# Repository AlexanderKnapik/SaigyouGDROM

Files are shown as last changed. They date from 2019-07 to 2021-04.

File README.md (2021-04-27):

SaigyouGDROM
========

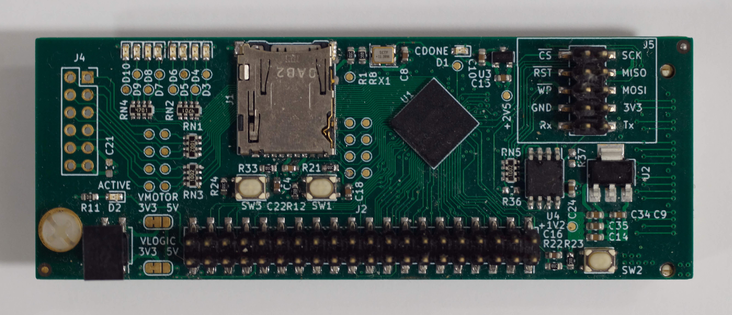
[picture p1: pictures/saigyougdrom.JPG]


SaigyouGDROM is a redesigned hardware implementation for Marcus Comstedt's
"iceGDROM". The aim of the project is to use the original software and gateware,
but with the hardware redesigned for a complete package.

This is currently a work in progress. Although the first revision prototypes have
been manufactured, there is still a lot to do in regards for testing and
recompiling the firmware and gateware for the new hardware.

For more information, please do visit the [original project](https://github.com/zeldin/iceGDROM).

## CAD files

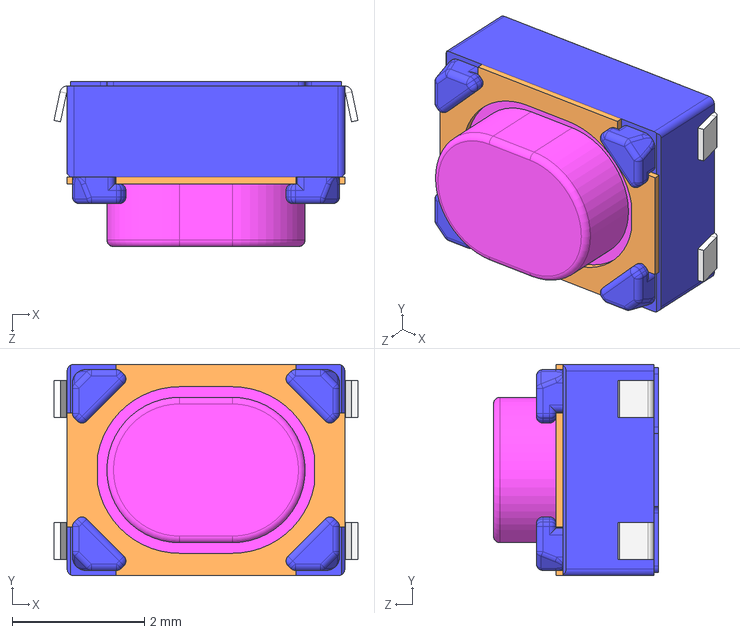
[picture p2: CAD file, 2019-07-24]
pcb/iceGDROM/3D/SKRPAB.STEP
4.60 x 3.20 x 2.50 mm

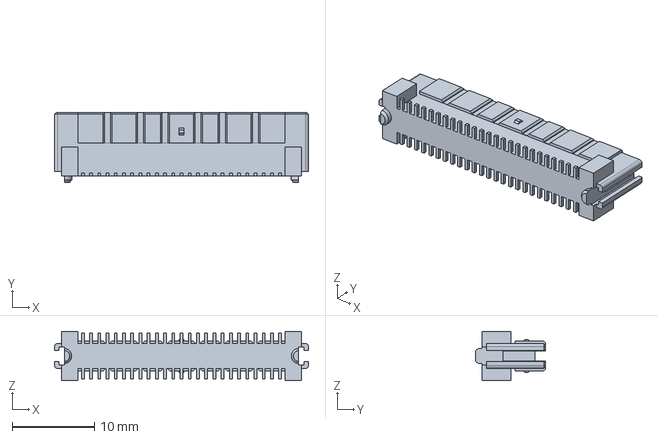
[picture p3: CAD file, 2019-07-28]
pcb/iceGDROM/3D/526020579.stp
30.9 x 8.50 x 6.00 mm

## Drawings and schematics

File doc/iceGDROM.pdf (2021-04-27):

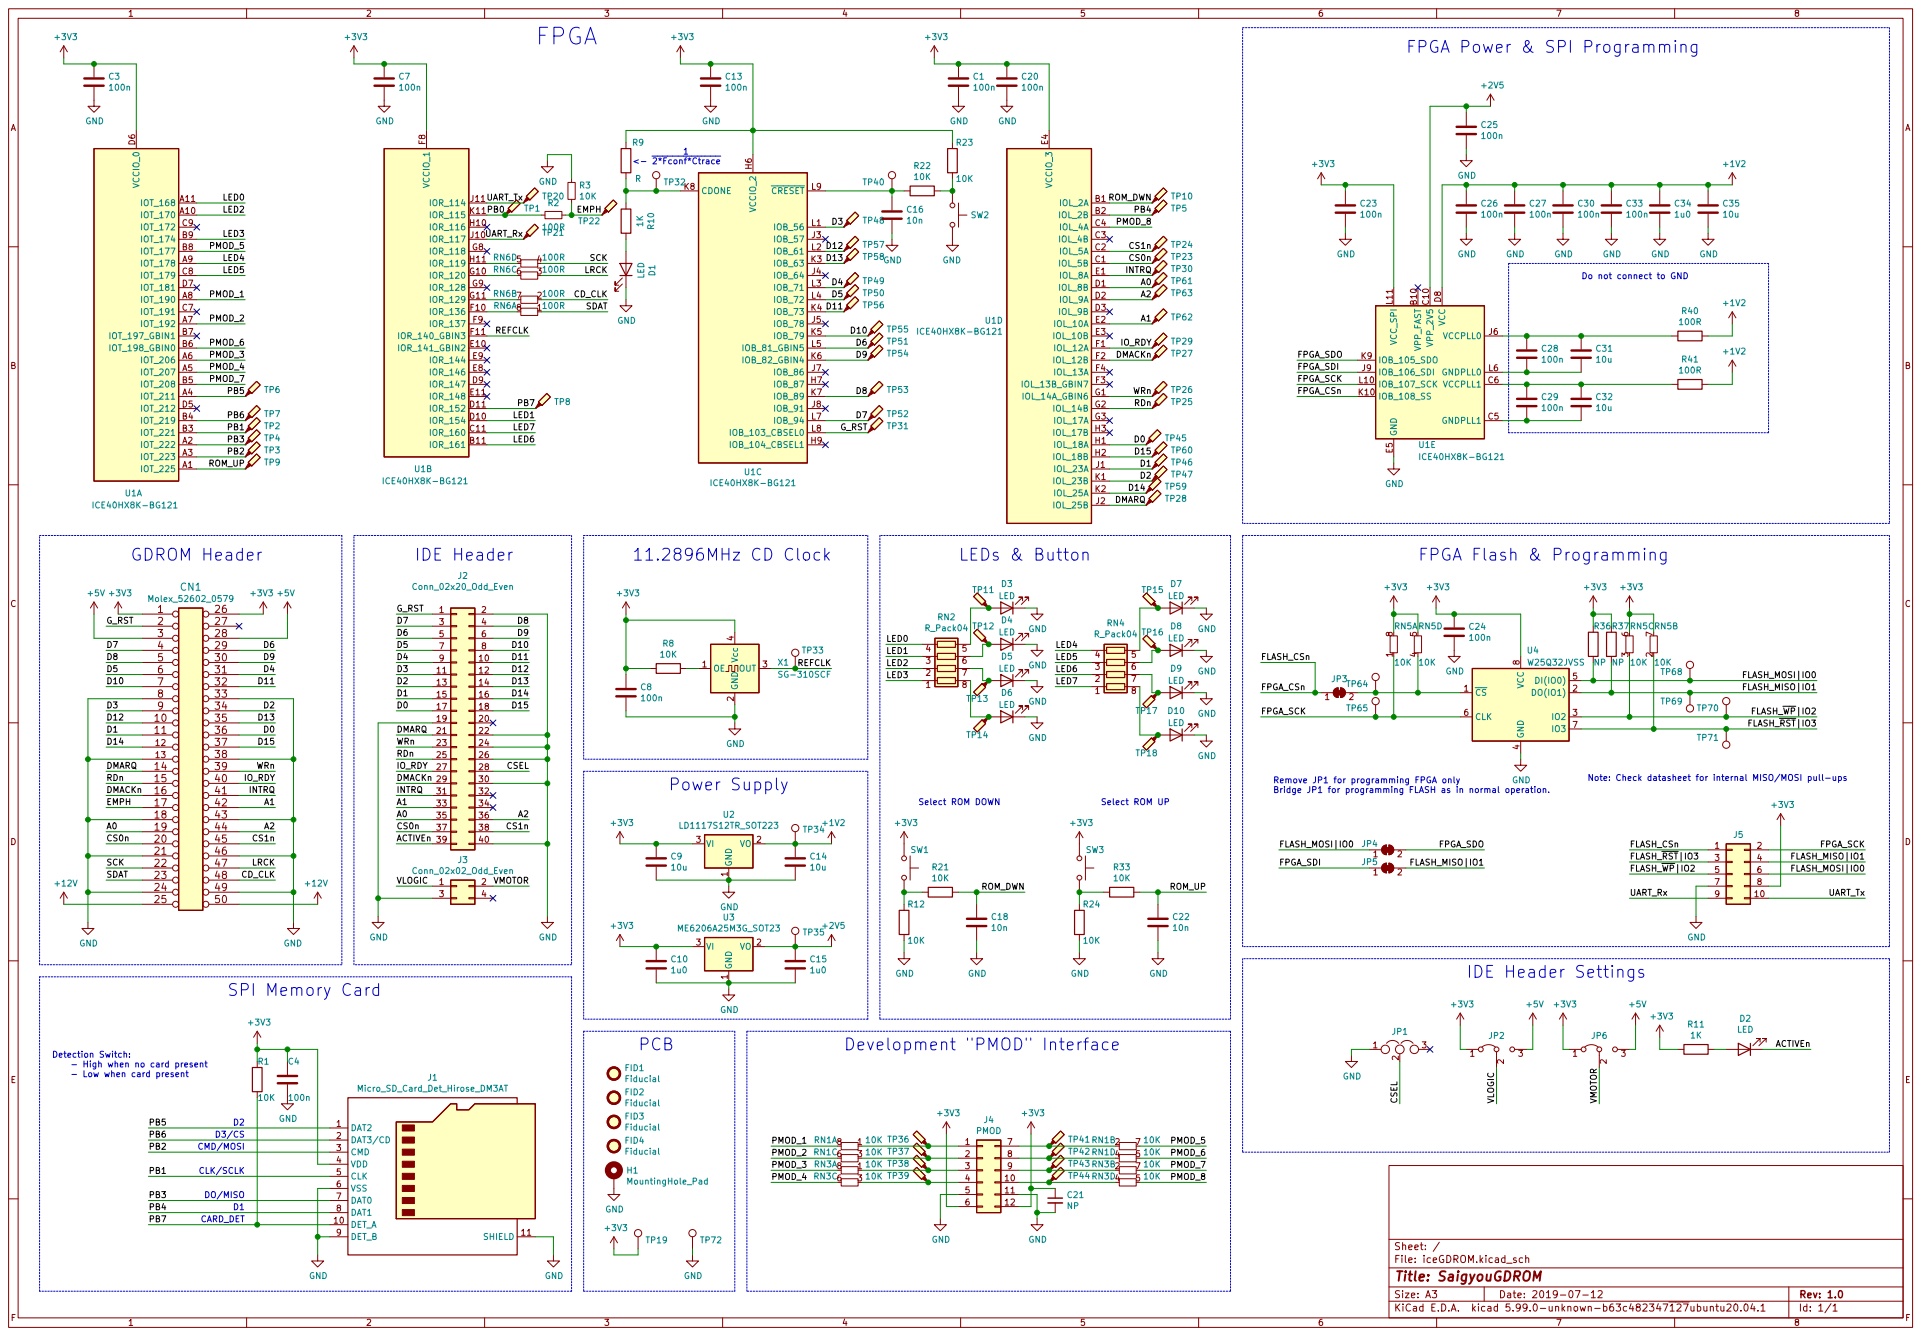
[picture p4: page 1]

FPGA Power & SPI Programming

Do not connect to GND

Note: Check datasheet for internal MISO/MOSI pull-ups

Remove JP1 for programming FPGA only
Bridge JP1 for programming FLASH as in normal operation.

D2 CARD_DET Detection Switch:
- High when no card present

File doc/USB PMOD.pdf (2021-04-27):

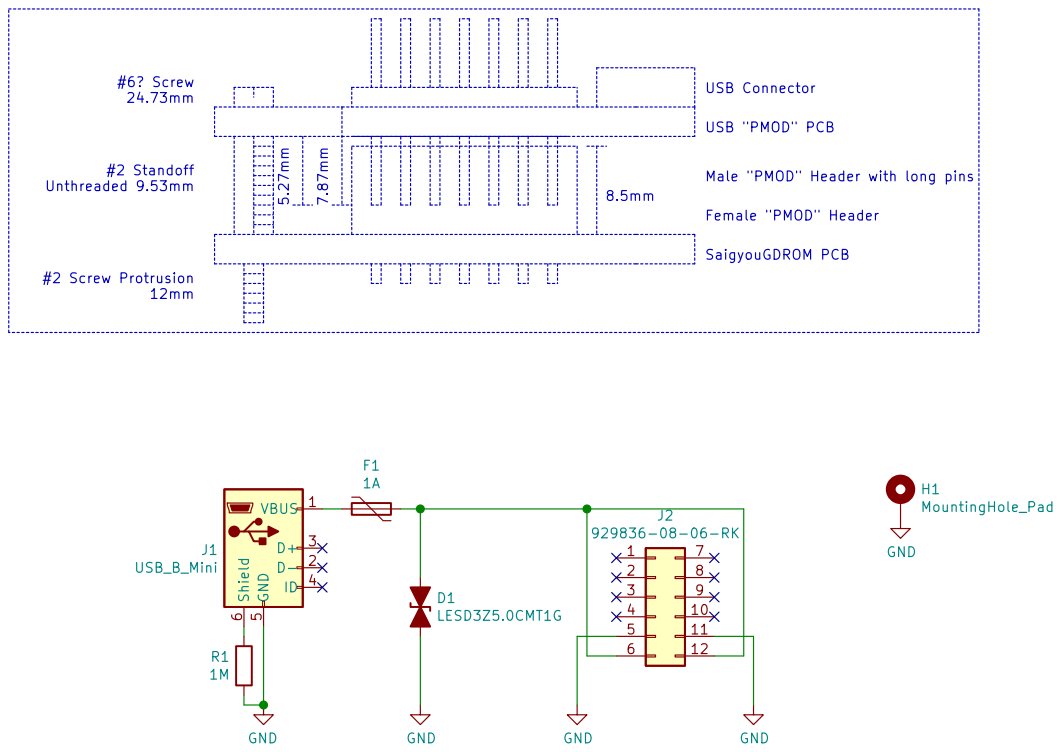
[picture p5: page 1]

File: USB PMOD.kicad_sch Sheet: /
Id: 1/1 Title:

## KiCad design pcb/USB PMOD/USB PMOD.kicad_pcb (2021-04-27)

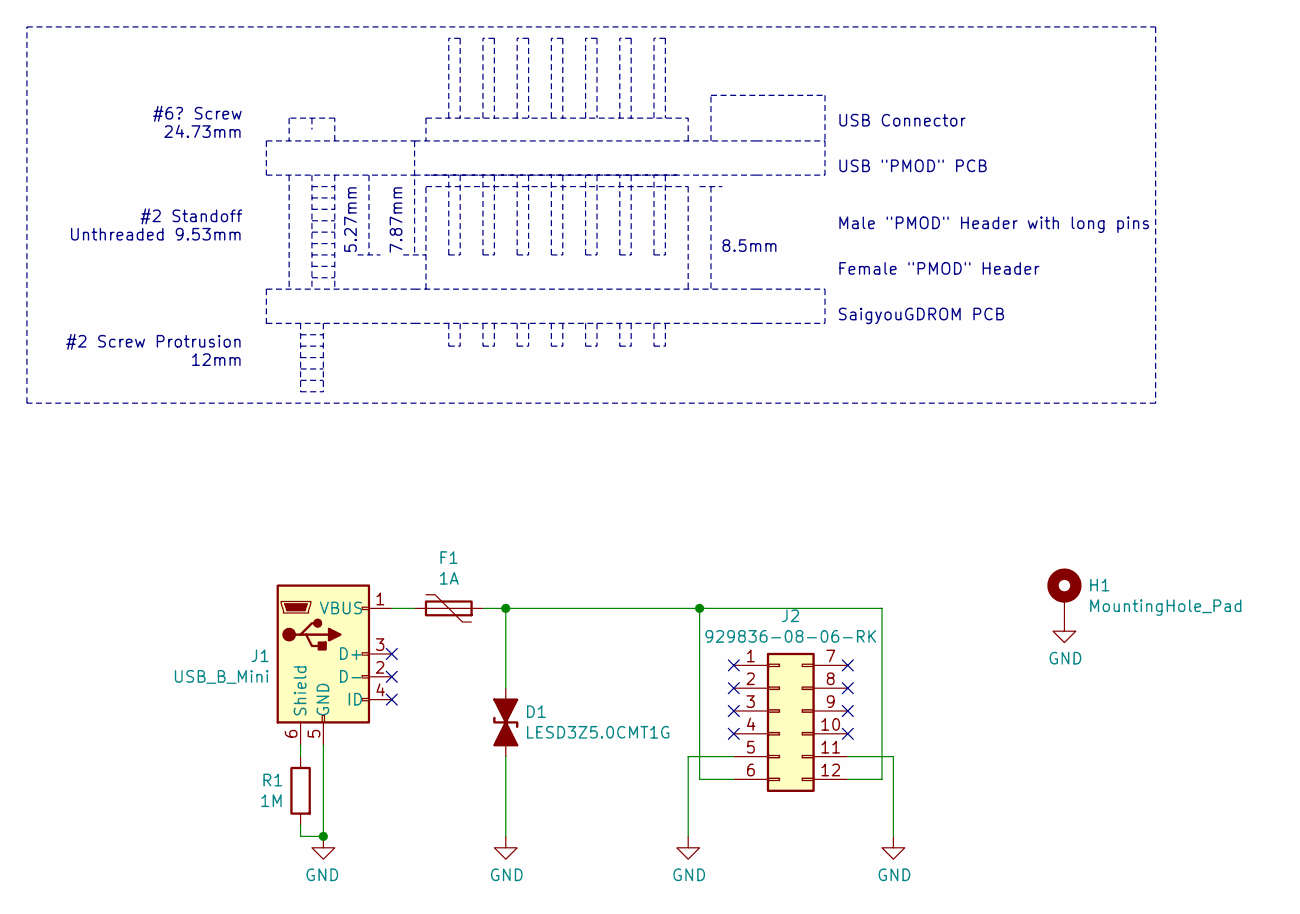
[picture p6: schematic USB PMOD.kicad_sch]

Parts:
D1: LESD3Z5.0CMT1G; D_SOD-323
F1: 1A; Fuse_1210_3225Metric_Castellated
H1: MountingHole_Pad; MountingHole_3.2mm_M3_Pad_Via
J1: USB_B_Mini; USB_Mini-B_Molex_657031020_Horizontal
J2: 929836-08-06-RK; PMOD_Host_2x06_P2.54mm_Vertical
R1: 1M; R_0603_1608Metric

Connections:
GND: D1.1 (A1), H1.1, J1.5 (GND), J2.5, J2.11, R1.2
unnamed: D1.2 (A2), F1.1, J2.6, J2.12
unnamed: F1.2, J1.1 (VBUS)
unnamed: J1.6 (Shield), R1.1

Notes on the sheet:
#6? Screw 24.73mm
#2 Standoff Unthreaded 9.53mm
#2 Screw Protrusion 12mm
5.27mm
7.87mm
8.5mm
USB Connector
USB "PMOD" PCB
Male "PMOD" Header with long pins
Female "PMOD" Header
SaigyouGDROM PCB

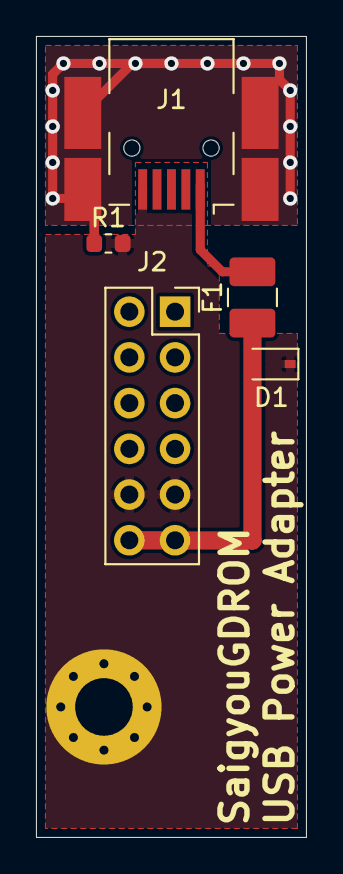
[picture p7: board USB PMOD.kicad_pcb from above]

Board: 2 copper layers, 15.0 x 44.5 mm, 6 parts (0 on the bottom side), 4 nets.

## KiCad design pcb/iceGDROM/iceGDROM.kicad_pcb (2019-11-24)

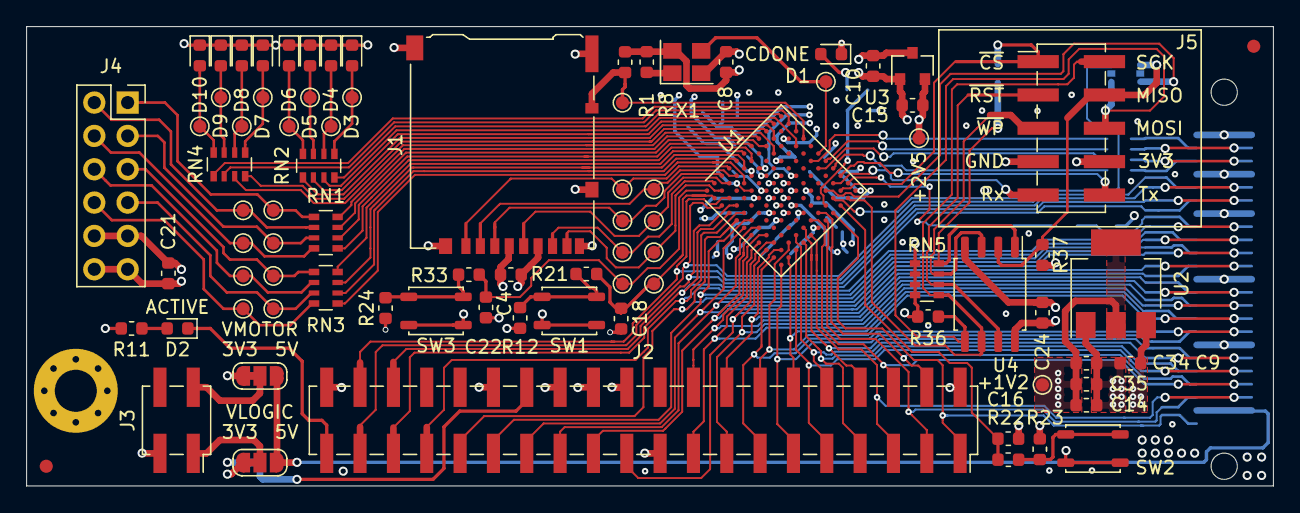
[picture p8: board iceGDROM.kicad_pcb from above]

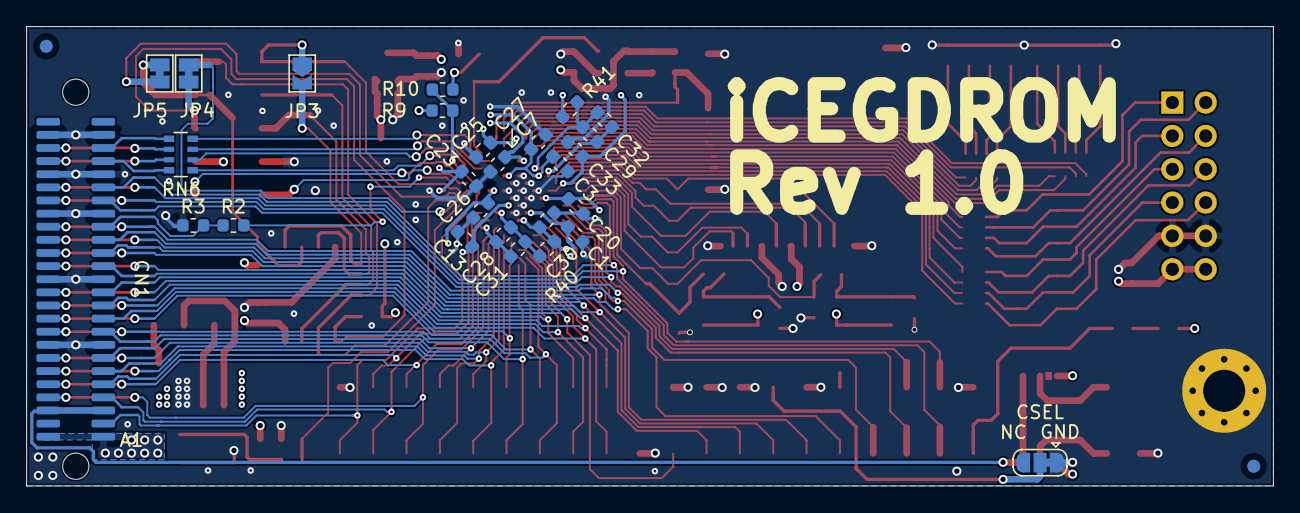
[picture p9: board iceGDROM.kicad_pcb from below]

Board: 4 copper layers, 95.0 x 35.0 mm, 114 parts (29 on the bottom side), 113 nets.

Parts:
+1V2, +2V5: TestPoint; TestPoint_Pad_D1.0mm
C1, C3, C4, C7, C8, C13, C20, C23, C24, C25, C26, C27, C28, C29, C30, C33: 100n; C_0603_1608Metric
C9, C14, C31, C32, C35: 10u; C_0603_1608Metric
C10, C15, C34: 1u0; C_0603_1608Metric
C16, C18, C22: 10n; C_0603_1608Metric
C21: NP; C_0603_1608Metric
CN1: Molex_52602_0579; Molex_052602_0579
D1, D2, D3, D4, D5, D6, D7, D8, D9, D10: LED; LED_0603_1608Metric
FID1, FID2, FID3, FID4: Fiducial; Fiducial_1mm_Mask2mm
H1: MountingHole_Pad; MountingHole_3.2mm_M3_Pad_Via
J1: Micro_SD_Card_Det_Hirose_DM3AT; microSD_HC_Hirose_DM3AT-SF-PEJM5
J2: Conn_02x20_Odd_Even; PinSocket_2x20_P2.54mm_Vertical_SMD
J3: Conn_02x02_Odd_Even; PinSocket_2x02_P2.54mm_Vertical_SMD
J4: PMOD; PMOD_Host_2x06_P2.54mm_Vertical
J5: Conn_02x05_Odd_Even; PinHeader_2x05_P2.54mm_Vertical_SMD
JP1: Jumper_NC_Dual; SolderJumper-3_P1.3mm_Bridged12_RoundedPad1.0x1.5mm
JP2, JP6: Jumper_3_Bridged12; SolderJumper-3_P1.3mm_Bridged12_RoundedPad1.0x1.5mm_NumberL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
JP3: SolderJumper_2_Bridged; SolderJumper-2_P1.3mm_Open_TrianglePad1.0x1.5mm
JP4, JP5: Jumper_NC_Small; SolderJumper-2_P1.3mm_Bridged_Pad1.0x1.5mm
R1, R3, R8, R12, R21, R22, R23, R24, R33: 10K; R_0603_1608Metric
R2, R40, R41: 100R; R_0603_1608Metric
R9: R; R_0603_1608Metric
R10, R11: 1K; R_0603_1608Metric
R36, R37: NP; R_0603_1608Metric
RN1, RN3, RN5: 10K; R_Array_Convex_4x0603
RN2, RN4: R_Pack04; R_Array_Convex_4x0603
RN6: 100R; R_Array_Convex_4x0603
SW1, SW2, SW3: SW_Push; SW_Push_SPST_NO_Alps_SKRP
TP2, TP3, TP4, TP5, TP6, TP7, TP8, TP9, TP10, TP11, TP12, TP13, TP14, TP15, TP16, TP17, TP18, TP36, TP37, TP38, TP39, TP41, TP42, TP43, TP44: TestPoint_Probe; TestPoint_Pad_D1.0mm
TP33: TestPoint; TestPoint_Pad_D1.0mm
U1: ICE40HX8K-BG121; BGA-121_9.0x9.0mm_Layout11x11_P0.8mm_Ball0.4mm_Pad0.35mm_NS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
U2: LD1117S12TR_SOT223; SOT-223-3_TabPin2
U3: ME6206A25M3G_SOT23; SOT-23
U4: W25Q32JVSS; SOIC-8_5.23x5.23mm_P1.27mm
X1: SG-310SCF; Crystal_SMD_3225-4Pin_3.2x2.5mm

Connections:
+1V2: +1V2.1, C14.1, C26.1, C27.1, C30.1, C33.1, C34.1, C35.1, R40.1, R41.1, U1.D4, U1.D8, U1.H4, U1.H8, U2.2
+2V5: +2V5.1, C15.1, C25.1, U1.C10, U3.2
+3V3: C1.2, C3.2, C4.1, C7.2, C8.1, C9.1, C10.1, C13.2, C20.2, C21.1, C23.1, C24.1, CN1.1, CN1.26, J1.4, J4.6, J4.12, J5.8, JP2.1, JP6.1, R1.1, R8.2, R9.2, R11.2, R23.2, R36.1, R37.1, RN5.5, RN5.6, RN5.7, RN5.8, SW1.1, SW3.1, U1.D6, U1.E4, U1.F8, U1.G4, U1.H6, U1.L11, U2.3, U3.3, U4.8, X1.4
+5V: CN1.3, CN1.28, JP2.3, JP6.3
+12V: CN1.25, CN1.50
/A0: CN1.19, J2.35, U1.D1
/A1: CN1.42, J2.33, U1.E2
/A2: CN1.44, J2.36, U1.D2
/ACTIVEn: D2.1, J2.39
/CD_CLK: CN1.48, RN6.2
/CS0n: CN1.20, J2.37, U1.C1
/CS1n: CN1.45, J2.38, U1.C2
/CSEL: J2.28, JP1.2
/D0: CN1.36, J2.17, U1.H1
/D1: CN1.11, J2.15, U1.J1
/D2: CN1.34, J2.13, U1.K1
/D3: CN1.9, J2.11, U1.L1
/D4: CN1.31, J2.9, U1.L3
/D5: CN1.6, J2.7, U1.L4
/D6: CN1.29, J2.5, U1.L5
/D7: CN1.4, J2.3, U1.L7
/D8: CN1.5, J2.4, U1.K7
/D9: CN1.30, J2.6, U1.K6
/D10: CN1.7, J2.8, U1.K5
/D11: CN1.32, J2.10, U1.K4
/D12: CN1.10, J2.12, U1.L2
/D13: CN1.35, J2.14, U1.K3
/D14: CN1.12, J2.16, U1.K2
/D15: CN1.37, J2.18, U1.H2
/DMACKn: CN1.16, J2.29, U1.F2
/DMARQ: CN1.14, J2.21, U1.J2
/EMPH: CN1.17, R2.1, R3.2
/FLASH_CSn: J5.1, JP3.1, U1.K10
/FLASH_MISO|IO1: J5.4, JP5.2, R37.2, U4.2
/FLASH_MOSI|IO0: J5.6, JP4.1, R36.2, U4.5
/FLASH_~RST~|IO3: J5.3, RN5.2, U4.7
/FLASH_~WP~|IO2: J5.5, RN5.3, U4.3
/FPGA_SCK: J5.2, RN5.1, U1.L10, U4.6
/FPGA_SDI: JP5.1, U1.J9
/FPGA_SDO: JP4.2, U1.K9
/G_RST: CN1.2, J2.1, U1.L8
/INTRQ: CN1.41, J2.31, U1.E1
/IO_RDY: CN1.40, J2.27, U1.F1
/LED0: RN2.4, U1.A11
/LED1: RN2.3, U1.D10
/LED2: RN2.2, U1.A10
/LED3: RN2.1, U1.B9
/LED4: RN4.4, U1.A9
/LED5: RN4.3, U1.C8
/LED6: RN4.2, U1.B11
/LED7: RN4.1, U1.C11
/LRCK: CN1.47, RN6.3
/PB0: R2.2, U1.K11
/PB1: J1.5, TP2.1, U1.B3
/PB2: J1.3, TP3.1, U1.A3
/PB3: J1.7, TP4.1, U1.A2
/PB4: J1.8, TP5.1, U1.B2
/PB5: J1.1, TP6.1, U1.A4
/PB6: J1.2, TP7.1, U1.B4
/PB7: J1.10, R1.2, TP8.1, U1.D11
/PMOD_1: RN1.8, U1.A8
/PMOD_2: RN1.6, U1.A7
/PMOD_3: RN3.8, U1.A6
/PMOD_4: RN3.6, U1.A5
/PMOD_5: RN1.7, U1.B8
/PMOD_6: RN1.5, U1.B6
/PMOD_7: RN3.7, U1.B5
/PMOD_8: RN3.5, U1.C4
/RDn: CN1.15, J2.25, U1.G2
/REFCLK: TP33.1, U1.F11, X1.3
/ROM_DWN: C18.1, R21.1, TP10.1, U1.B1
/ROM_UP: C22.1, R33.1, TP9.1, U1.A1
/SCK: CN1.22, RN6.4
/SDAT: CN1.23, RN6.1
/UART_Rx: J5.9, U1.J10
/UART_Tx: J5.10, U1.J11
/VLOGIC: J3.1, JP2.2
/VMOTOR: J3.2, JP6.2
/WRn: CN1.39, J2.23, U1.G1
GND: C1.1, C3.1, C4.2, C7.1, C8.2, C9.2, C10.2, C13.1, C14.2, C15.2, C16.1, C18.2, C20.1, C21.2, C22.2, C23.2, C24.2, C25.2, C26.2, C27.2, C30.2, C33.2, C34.2, C35.2, CN1.8, CN1.13, CN1.18, CN1.21, CN1.24, CN1.33, CN1.38, CN1.43, CN1.46, CN1.49, D1.1, D3.1, D4.1, D5.1, D6.1, D7.1, D8.1, D9.1, D10.1, H1.1, J1.6, J1.9, J1.11, J2.2, J2.19, J2.22, J2.24, J2.26, J2.30, J2.40, J3.3, J4.5, J4.11, J5.7, JP1.1, R3.1, R12.1, R24.1, SW2.2, U1.E5, U1.E6, U1.E7, U1.F5, U1.F6, U1.F7, U1.G5, U1.G6, U1.G7, U1.H5, U2.1, U3.1, U4.4, X1.2
unnamed: C16.2, R22.1, U1.L9
unnamed: C28.1, C31.1, R40.2, U1.J6
unnamed: C28.2, C31.2, U1.L6
unnamed: C29.1, C32.1, R41.2, U1.C6
unnamed: C29.2, C32.2, U1.C5
unnamed: D1.2, R10.2
unnamed: D2.2, R11.1
unnamed: D3.2, RN2.5, TP11.1
unnamed: D4.2, RN2.6, TP12.1
unnamed: D5.2, RN2.7, TP13.1
unnamed: D6.2, RN2.8, TP14.1
unnamed: D7.2, RN4.5, TP15.1
unnamed: D8.2, RN4.6, TP16.1
unnamed: D9.2, RN4.7, TP17.1
unnamed: D10.2, RN4.8, TP18.1
unnamed: J4.1, RN1.1, TP36.1
unnamed: J4.2, RN1.3, TP37.1
unnamed: J4.3, RN3.1, TP38.1
unnamed: J4.4, RN3.3, TP39.1
unnamed: J4.7, RN1.2, TP41.1
unnamed: J4.8, RN1.4, TP42.1
unnamed: J4.9, RN3.2, TP43.1
unnamed: J4.10, RN3.4, TP44.1
unnamed: JP3.2, RN5.4, U4.1
unnamed: R8.1, X1.1
unnamed: R9.1, R10.1, U1.K8
unnamed: R12.2, R21.2, SW1.2
unnamed: R22.2, R23.1, SW2.1
unnamed: R24.2, R33.2, SW3.2
unnamed: RN6.5, U1.H11
unnamed: RN6.6, U1.G10
unnamed: RN6.7, U1.G11
unnamed: RN6.8, U1.F10

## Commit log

2019-07-18 Adding work so far on an integrated PCB schematic.
    [iceGDROM.kicad_pcb, iceGDROM.sch]
2019-07-24 Included the SPI Memory card into the schematic as a major point. Created a footprint for the tactile button being used and including the 3D model due to no NC clause.
    [SKRPAB.STEP, iceGDROM.kicad_pcb, iceGDROM.sch]
2019-07-27 Finishing up the peripherals for the FPGA in the schematic, adding the CRESET and CDONE circuits and decoupling for IO power pins.
    [iceGDROM.kicad_pcb, iceGDROM.sch]
2019-07-28 Completed a functional version of the schematic and started with basic layout of the components on the PCB.
    [iceGDROM.kicad_pcb, iceGDROM.sch]
2019-07-28 Fixing the Molex header pin position and adding a 3D model path to it.
2019-07-28 Split the IDE header into 40+4 due to SMD header availability. Started with layout of the PCB.
    [526020579.stp, iceGDROM.kicad_pcb, iceGDROM.sch]
2019-08-23 Completed functionality of the PCB layout. Still have to do the silkscreen though.
    [iceGDROM.kicad_pcb, iceGDROM.sch]
2019-11-24 Finalising the silkscreen & the schematic page
    [iceGDROM.kicad_pcb, iceGDROM.sch]
2021-04-27 Adding latest hardware changes and including USB PMOD project for powering the unit for testing.
    [USB PMOD Panelised-B_Cu.gbl, USB PMOD Panelised-B_Mask.gbs, USB PMOD Panelised-B_Paste.gbp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]
2021-04-27 Deleting backup files from git repository, and updating the USB PMOD board to latest nightly build.
    [USB PMOD Panelised.kicad_pcb, USB PMOD.kicad_pcb, USB PMOD.kicad_sch]

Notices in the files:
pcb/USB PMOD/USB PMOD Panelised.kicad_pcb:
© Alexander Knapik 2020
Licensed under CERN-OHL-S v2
